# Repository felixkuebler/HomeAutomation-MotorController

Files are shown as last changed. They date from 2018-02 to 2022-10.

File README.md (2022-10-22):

# Introduction
Due to the growing demand of iot devices for home automation this project presents an cheap, easy to use and "open source" alternative to brand Products such as Phillips Hue. Based on the ESP8266-12E, a small WiFi enabled chipset, these devices can be retrofitted in a variety of devices such as light switches, motor controllers and more.

Each home automation node will access your local wifi network and is configurable through a webpage hosted locally on the device itsself. Your network needs to provide a [mqtt](https://pagefault.blog/2017/03/02/using-local-mqtt-broker-for-cloud-and-interprocess-communication/) broker to enable communication between nodes thus enabling its full functionality. An easy to use webinterface as well as a mqtt broker is provided by [Openhab](https://www.openhab.org/).

# Motor Controller
This small module can be mounted on any [Nema17](http://reprap.org/wiki/NEMA_17_Stepper_motor) stepper motor and thereby enabling Wifi functionality. The built in [TMC2130](https://www.trinamic.com/) stepper driver provides virtually silent motor operation as well as resistance detection of the driveshaft. This feature eliminates the need for endstops or any other sensor inputs thus resulting in a small and easy to use form factor. 

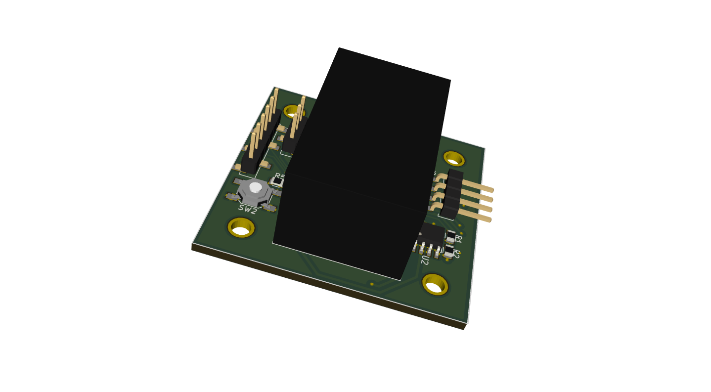
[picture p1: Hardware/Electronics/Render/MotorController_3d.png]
motor controller render


The current versions can be found here:
* *no release available*

# License
This work is property of Felix Kübler and is licensed under the
<a rel="license" href="http://creativecommons.org/licenses/by-nc/4.0/">Creative Commons Attribution-NonCommercial 4.0 International License</a>.

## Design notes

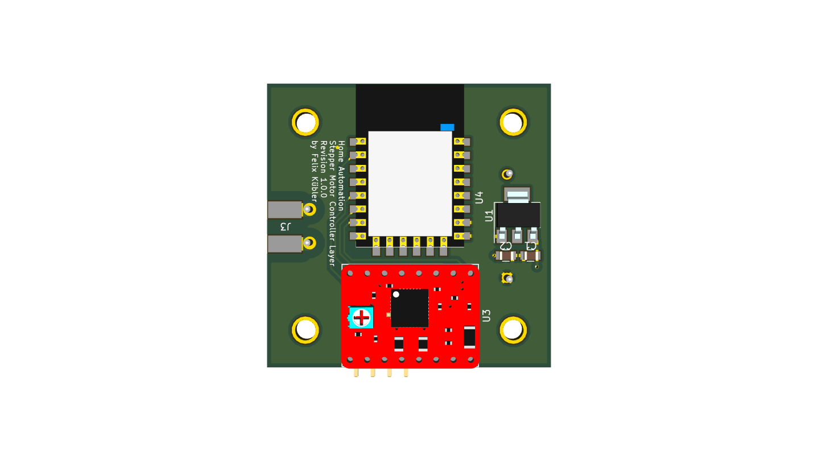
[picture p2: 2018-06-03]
Hardware/Electronics/Render/MotorController_bottom.png

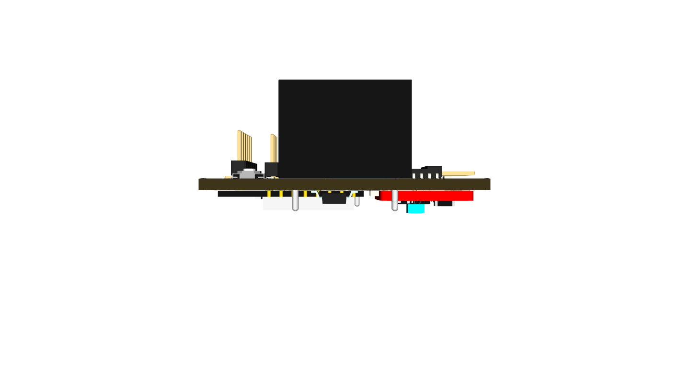
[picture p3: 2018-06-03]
Hardware/Electronics/Render/MotorController_right.png

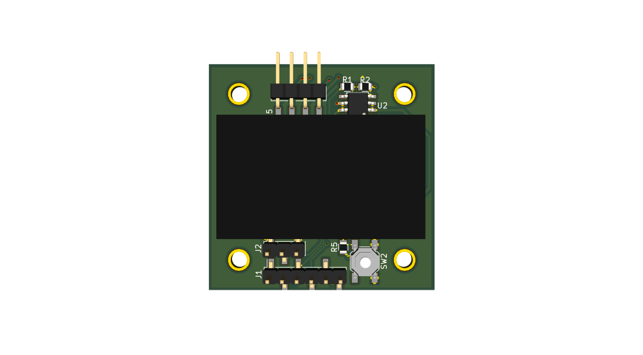
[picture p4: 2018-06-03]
Hardware/Electronics/Render/MotorController_top.png

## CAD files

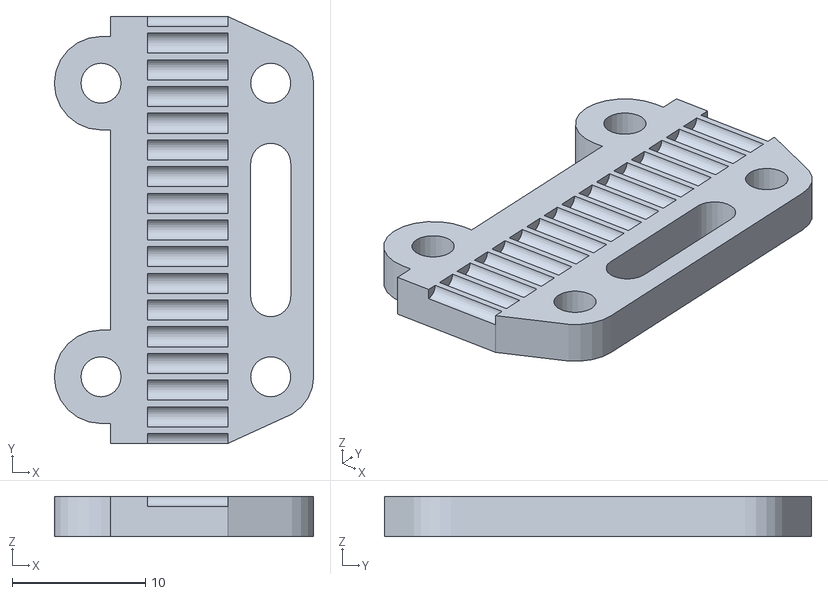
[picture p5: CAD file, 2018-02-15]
Hardware/Mechanics/PrintParts/BeltMountTeeth.stl
19.4 x 32.0 x 3.00

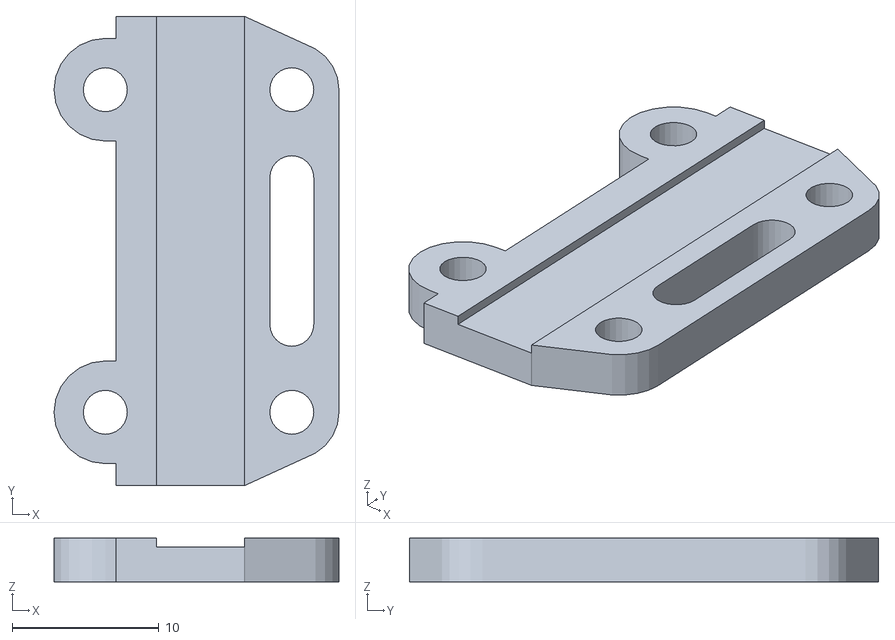
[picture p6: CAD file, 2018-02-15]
Hardware/Mechanics/PrintParts/BeltMountNoTeeth.stl
19.4 x 32.0 x 3.00

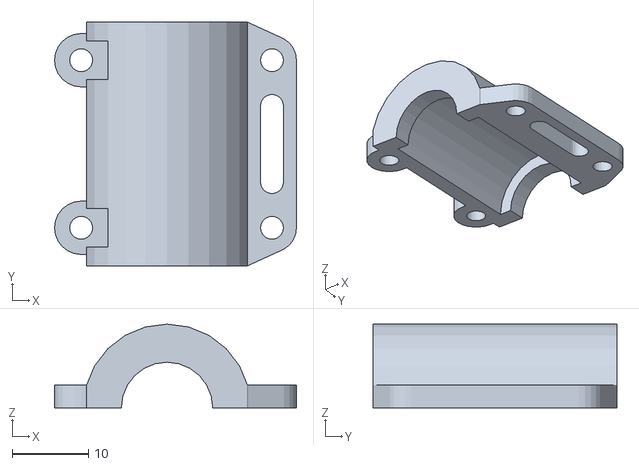
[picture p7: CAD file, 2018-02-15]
Hardware/Mechanics/PrintParts/BearingMount.stl
31.8 x 32.0 x 11.0

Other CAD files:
Hardware/TestAssembly/CAD/TestAssembly.skp

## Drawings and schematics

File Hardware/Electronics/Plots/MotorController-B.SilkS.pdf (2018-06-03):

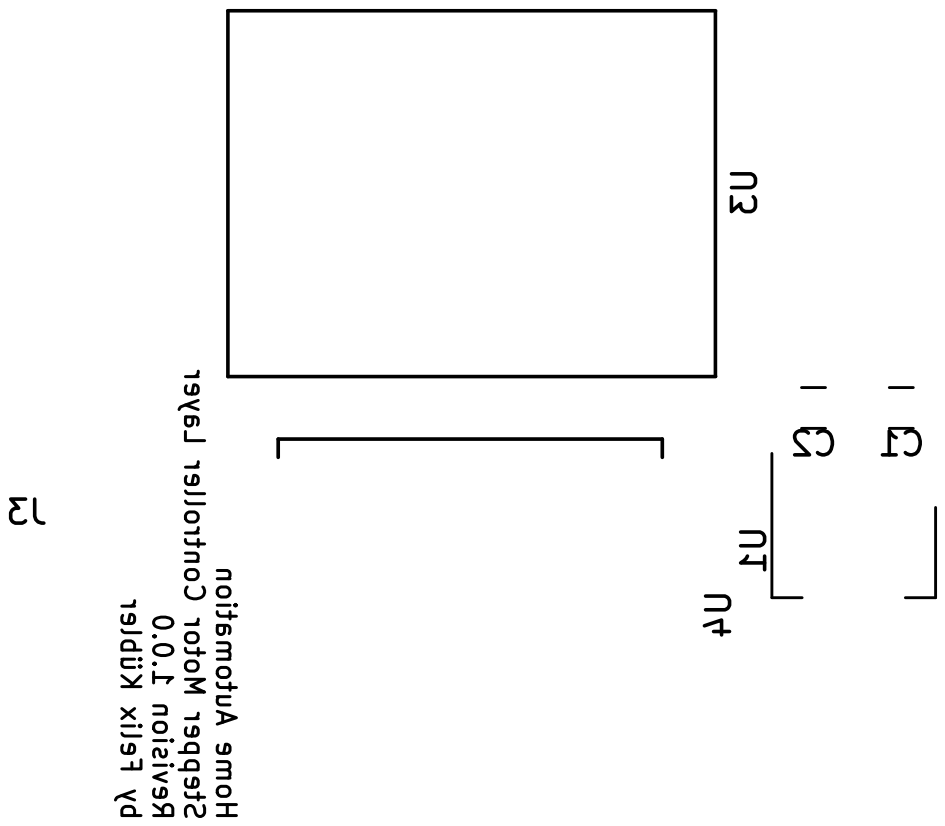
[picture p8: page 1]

by Felix Kübler Revision 1.0.0 Stepper Motor Controller Layer Home Automation U3 C2 C1 U1 U4

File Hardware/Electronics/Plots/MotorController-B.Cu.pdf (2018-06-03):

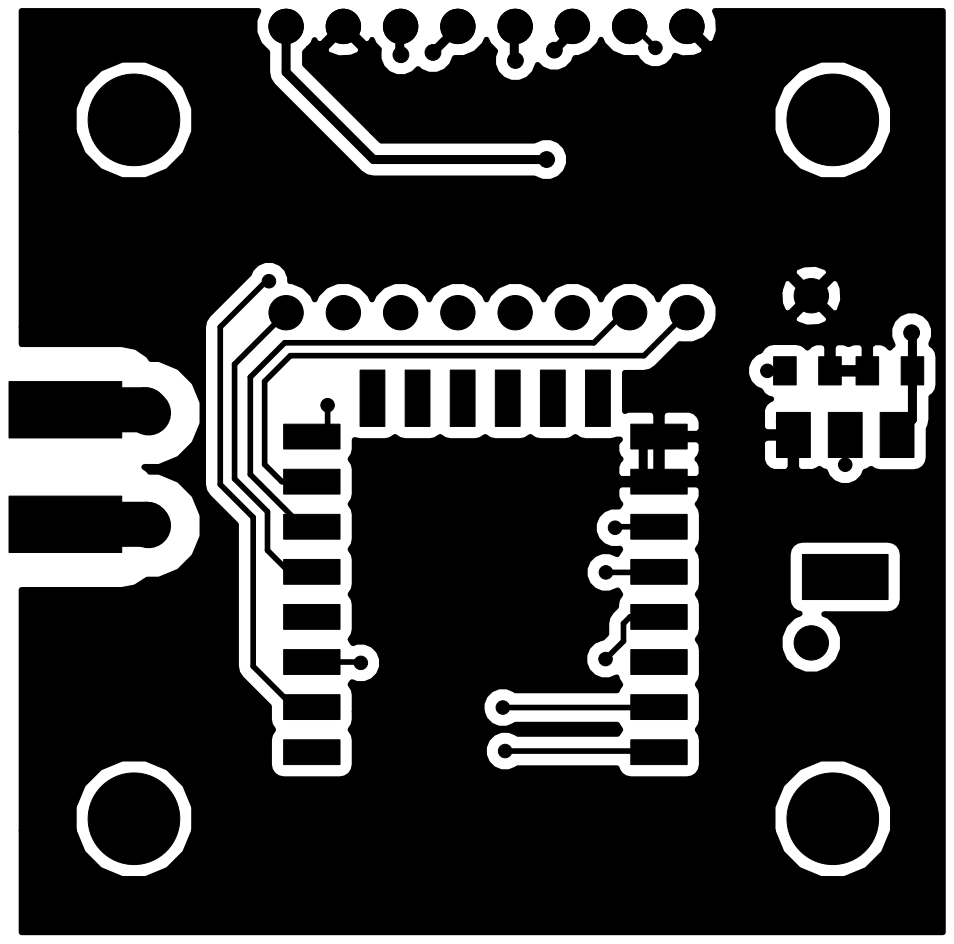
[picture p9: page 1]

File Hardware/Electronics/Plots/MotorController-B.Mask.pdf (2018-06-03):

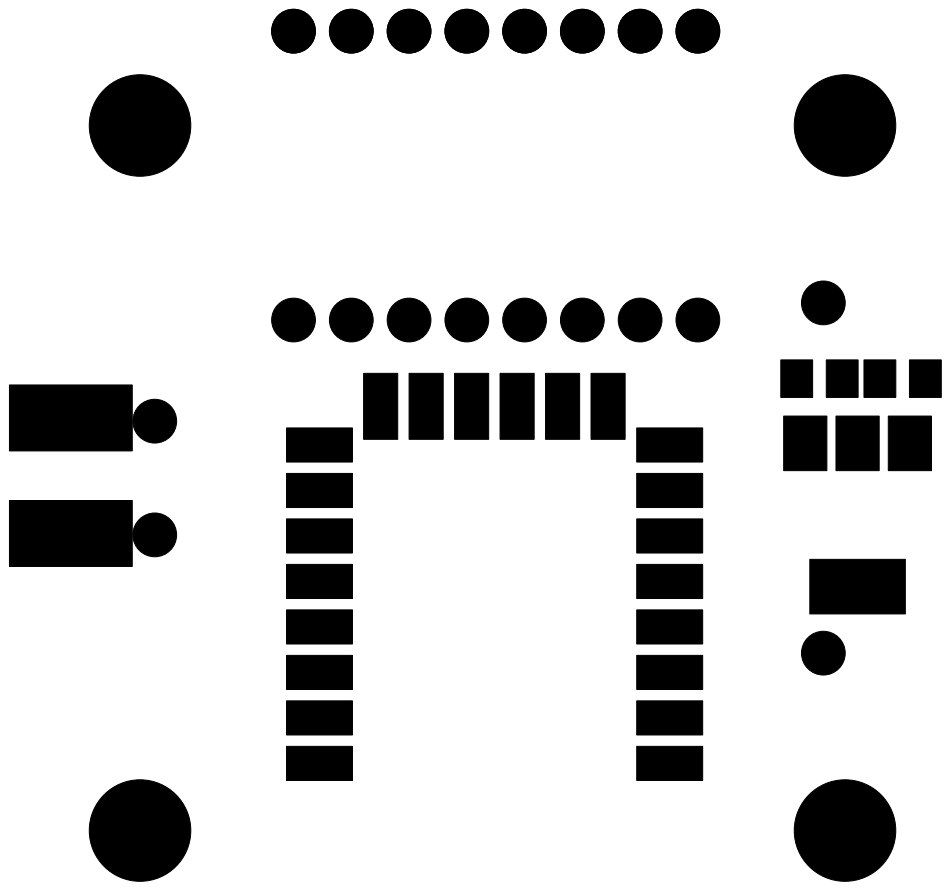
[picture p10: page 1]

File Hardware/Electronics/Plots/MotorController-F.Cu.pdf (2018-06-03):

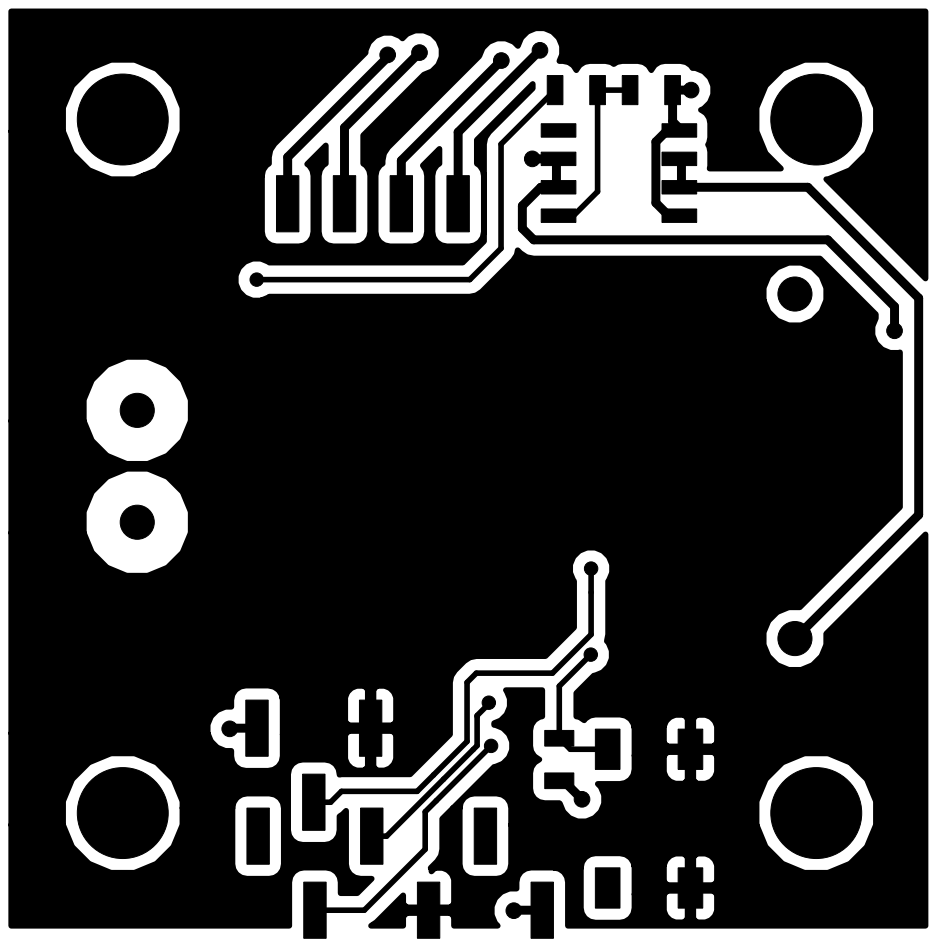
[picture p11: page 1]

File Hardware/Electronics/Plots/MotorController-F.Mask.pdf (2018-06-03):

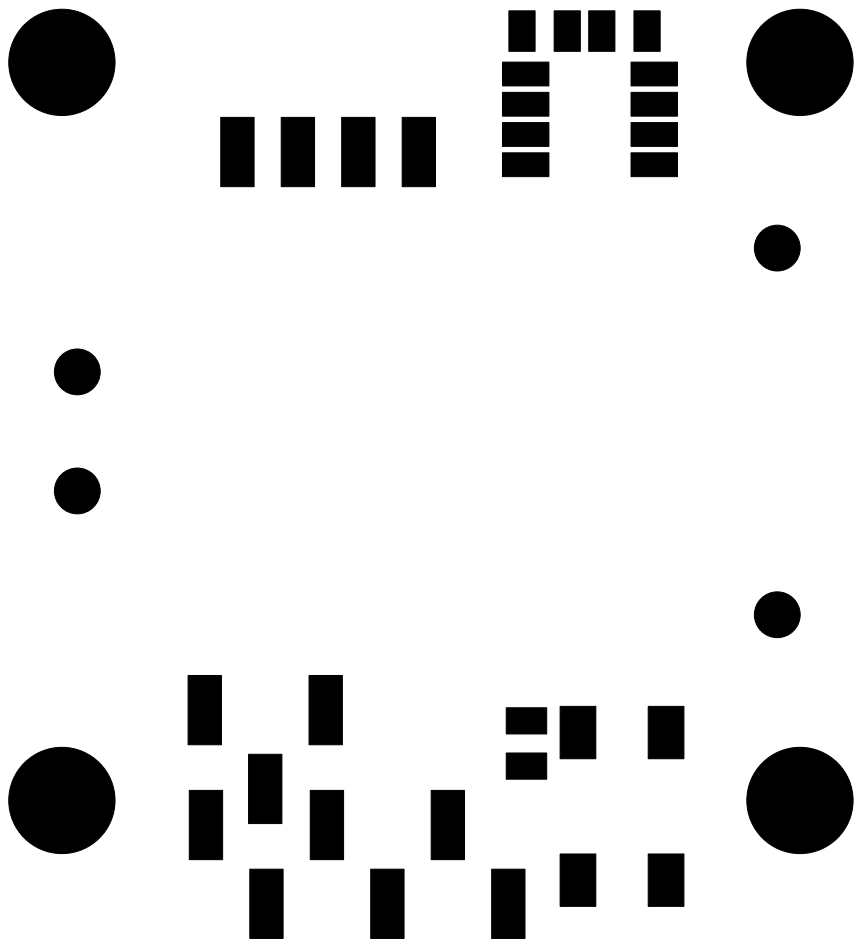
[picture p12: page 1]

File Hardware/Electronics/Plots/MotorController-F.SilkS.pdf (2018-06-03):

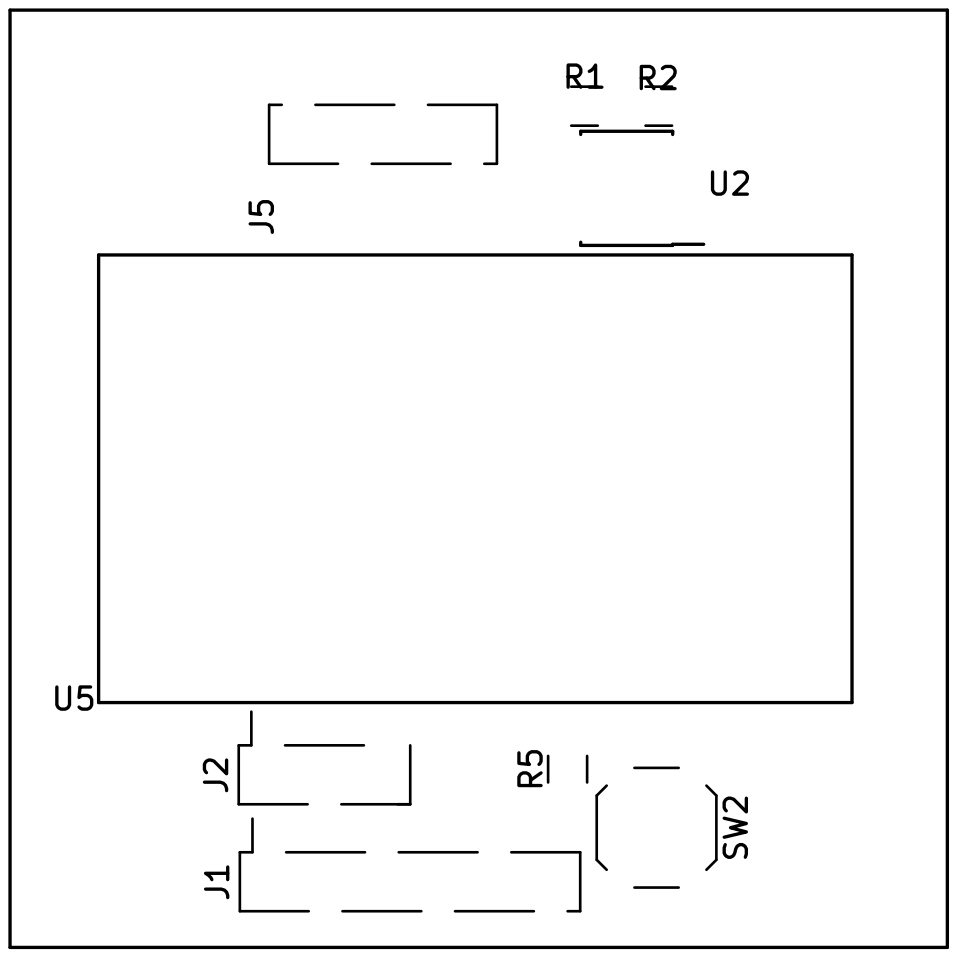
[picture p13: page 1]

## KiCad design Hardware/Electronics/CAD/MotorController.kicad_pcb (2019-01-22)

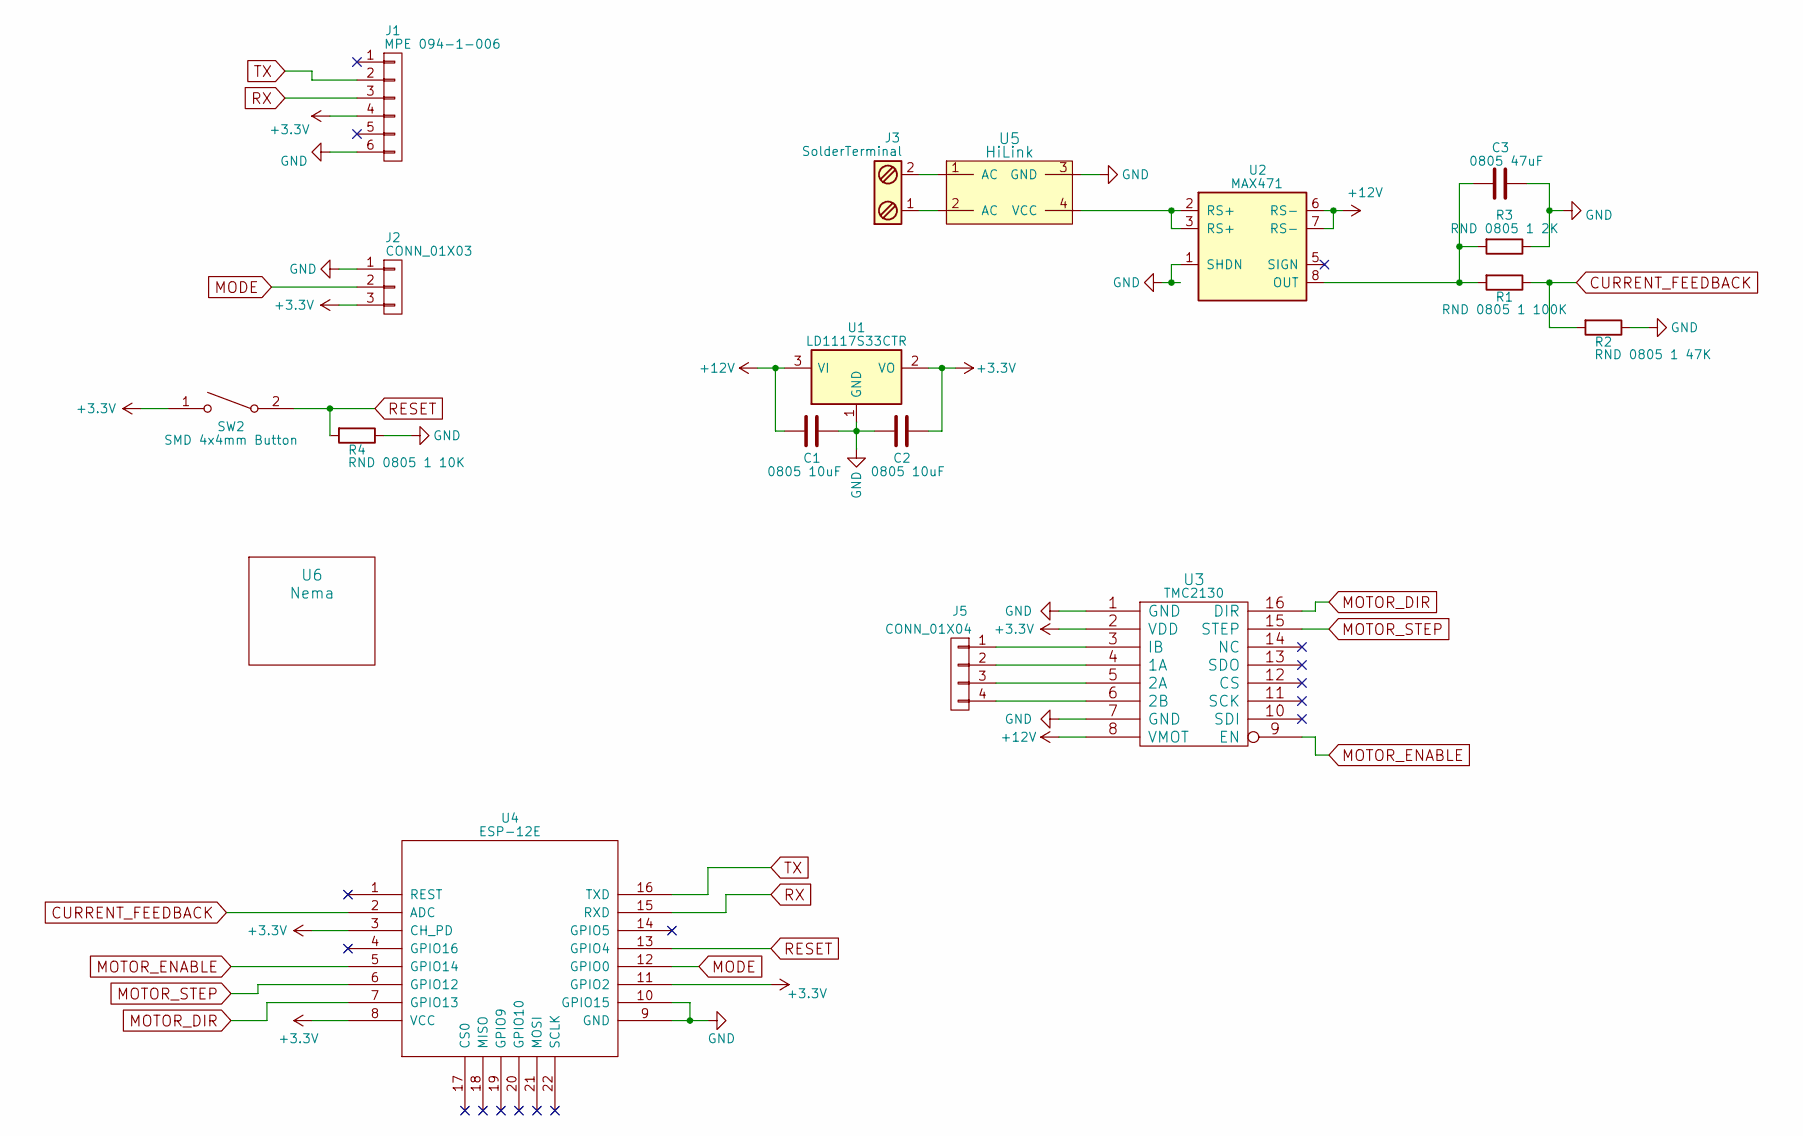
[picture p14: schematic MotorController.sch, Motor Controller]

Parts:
C1, C2: 0805 10uF; C_0805
C3: 0805 47uF; C_0805
J1: MPE 094-1-006; Pin_Header_Straight_1x06_Pitch2.54mm_SMD_Pin1Right
J2: CONN_01X03; Pin_Header_Straight_1x03_Pitch2.54mm_SMD_Pin1Right
J3: SolderTerminal; SolderPad_1x2_2.54mm
J5: CONN_01X04; Pin_Header_SMD_1x4_Angled_2.54mm
R1: RND 0805 1 100K; R_0805
R2: RND 0805 1 47K; R_0805
R3: RND 0805 1 2K; R_0805
R4: RND 0805 1 10K; R_0805
SW2: SMD 4x4mm Button; SW_SPST_SKQG
U1: LD1117S33CTR; SOT-223
U2: MAX471; SOIC-8_3.9x4.9mm_Pitch1.27mm
U3: TMC2130; TMC2230_SMD
U4: ESP-12E; ESP-12E_SMD
U5: HiLink; HLK-PM01
U6: Nema; Nema17

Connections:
+3V3: C2.1, J1.4, J2.3, SW2.1, U1.2 (VO), U3.2 (VDD), U4.3 (CH_PD), U4.8 (VCC), U4.11 (GPIO2)
+12V: C1.2, U1.3 (VI), U2.6 (RS-), U2.7 (RS-), U3.8 (VMOT)
CURRENT_FEEDBACK: R1.1, R2.2, U4.2 (ADC)
GND: C1.1, C2.2, C3.1, J1.6, J2.1, R2.1, R3.1, R4.1, U1.1 (GND), U2.1 (SHDN), U2.4 (GND), U3.1 (GND), U3.7 (GND), U4.9 (GND), U4.10 (GPIO15), U5.3 (GND)
MODE: J2.2, U4.12 (GPIO0)
MOTOR_DIR: U3.16 (DIR), U4.7 (GPIO13)
MOTOR_ENABLE: U3.9 (EN), U4.5 (GPIO14)
MOTOR_STEP: U3.15 (STEP), U4.6 (GPIO12)
unnamed: C3.2, R1.2, R3.2, U2.8 (OUT)
unnamed: J3.1, U5.2 (AC)
unnamed: J3.2, U5.1 (AC)
unnamed: J5.1, U3.3 (IB)
unnamed: J5.2, U3.4 (1A)
unnamed: J5.3, U3.5 (2A)
unnamed: J5.4, U3.6 (2B)
unnamed: U2.2 (RS+), U2.3 (RS+), U5.4 (VCC)
RESET: R4.2, SW2.2, U4.13 (GPIO4)
RX: J1.3, U4.15 (RXD)
TX: J1.2, U4.16 (TXD)

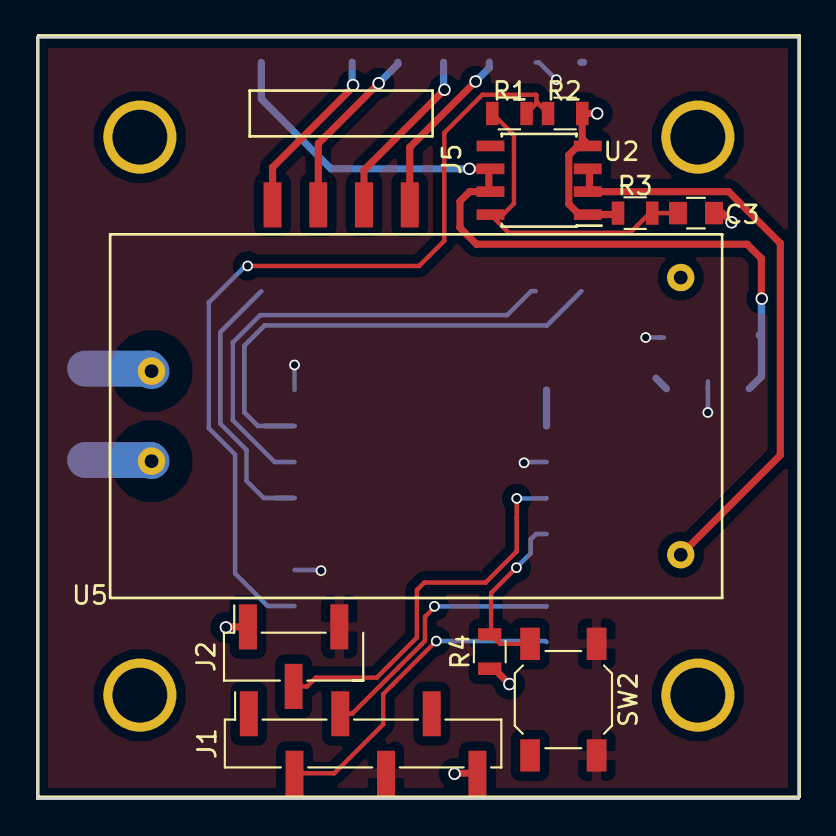
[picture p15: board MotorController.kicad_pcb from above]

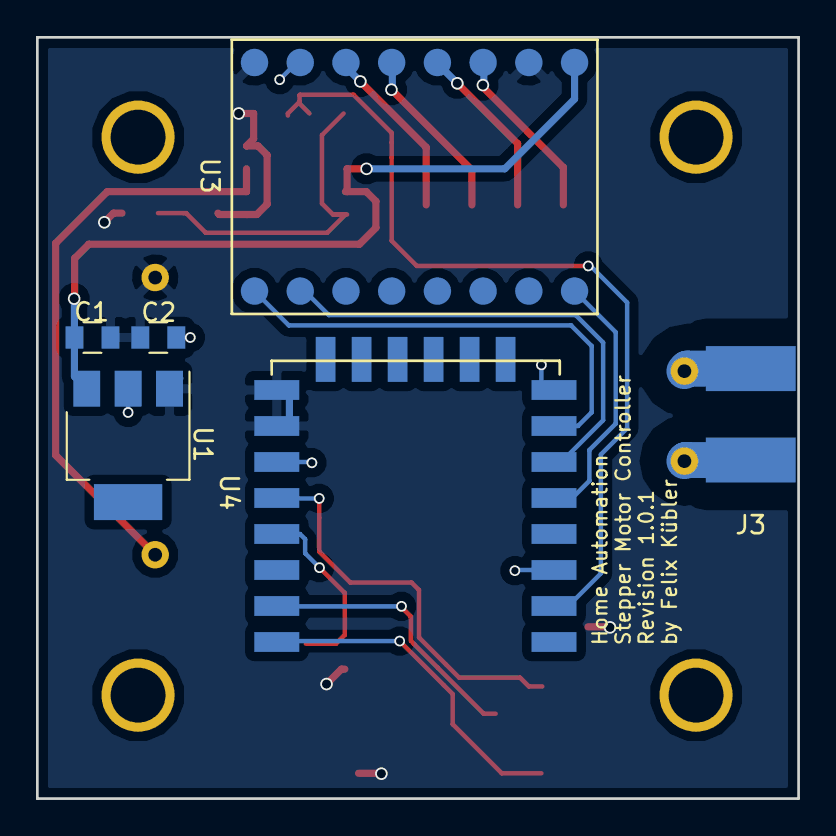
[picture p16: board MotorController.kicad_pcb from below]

Board: 2 copper layers, 42.3 x 42.3 mm, 18 parts (6 on the bottom side), 19 nets.

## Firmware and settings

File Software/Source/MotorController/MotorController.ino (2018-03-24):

#include <map>
#include <vector>

#include <ESP8266WiFi.h>

#include <DNSServer.h>
#include <ESP8266WebServer.h>
#include <WiFiClient.h> 
#include <PubSubClient.h>
#include <ESP8266HTTPUpdateServer.h>
#include <EEPROM.h>

#include "utils.h"
#include "motor_utils.h"
#include "wifi_utils.h"
#include "eeprom_utils.h"
#include "web_interface.h"


wifi_obj wifi_info;
motor_obj motor_info;

short int reset_pin;


DNSServer dnsServer;
ESP8266WebServer wifiServer(80);
WiFiClient wifiClient;
ESP8266HTTPUpdateServer wifiUpdater;
PubSubClient client(wifiClient);


CONFIG setup_type = default_config;
bool network_available = false;



/*
 * this function is called when a html request was send to the local html server
 */
void htmlHandleRequest() 
{
  //request counter
  short int request_count = 0;
  
  //get ssid request message from client
  String val = wifiServer.arg("wifi_ssid");
  //check if a message is not empty
  if(val.length()>0)
  {
    //set changes
    Serial.println("wifi_ssid : " + val);
    wifi_info.wifi_ssid = val;
    request_count++;
  }

  //get pw request message from client
  val = wifiServer.arg("wifi_pw");
  //check if a message is not empty
  if(val.length()>0)
  {
    //set changes
    Serial.println("wifi_pw : " + val);
    wifi_info.wifi_pw = val;
    request_count++;
  }

  //get host name request message from client
  val = wifiServer.arg("host_name");
  //check if a message is not empty
  if(val.length()>0)
  {
    //set changes
    Serial.println("host name : " + val);
    wifi_info.host_name = val;
    request_count++;
  }

  //get host name request message from client
  val = wifiServer.arg("host_pw");
  //check if a message is not empty
  if(val.length()>0)
  {
    //set changes
    Serial.println("host pw : " + val);
    wifi_info.host_pw = val;
    request_count++;
  }
  
  //get mqtt broker request message from client
  val = wifiServer.arg("mqtt_broker");
  //check if a message is not empty
  if(val.length()>0)
  {
    //set changes
    Serial.println("mqtt broker : " + val);
    wifi_info.mqtt_broker = val;
    request_count++;
  }

  //get motor topic request message from client
  val = wifiServer.arg("motor_topic");
  //check if a message is not empty
  if(val.length()>0)
  {
    //set changes
    Serial.println("motor_topic : " + val);
    motor_info.topic = val;
    request_count++;
  }

  //get motor range_extern request message from client
  val = wifiServer.arg("motor_range_extern");
  //check if a message is not empty
  if(val.length()>0)
  {
    //set changes
    Serial.println("motor_range_extern : " + val);
    motor_info.range_extern = val;
    request_count++;
  }

  //get motor calibration command request message from client
  val = wifiServer.arg("motor_calibration");
  //check if a message is not empty
  if(val.length()>0)
  {
    //set changes
    Serial.println("motor calibration triggered");
    calibrateMotor(motor_info);
    request_count++;
  }

  //get reset trigger from client
  String reset_settings = wifiServer.arg("reset_settings");
  //check if a reset was triggered
  if(reset_settings.length()>0)
  {
    Serial.println("System Settings set to default");
    //write reset flag to eeprom to use after a system reboot
    writeCharToEEPROM(0, 0);

    //reboot system
    ESP.eraseConfig();
    ESP.reset();
  }

  //get save trigger from client
  String save_settings = wifiServer.arg("save_settings");
  //check if reboot was triggered
  if(save_settings.length()>0)
  {
    Serial.println("user settings saved, system is going to restart");

    //save local changes to eeprom
    saveSettingsToEEPROM(wifi_info, motor_info);
    writeCharToEEPROM(0, 1);
    
    //reboot system
    ESP.eraseConfig();
    ESP.reset();
  }

  //give wifiServer new webpage
  wifiServer.send(200, "text/html", generateWebpage(wifi_info, motor_info));
}


/*
 * this function is called when a mqtt post was received
 */
void mqttSubscribeCallback(char* topic, byte* payload, unsigned int length) 
{  

  //turn byte* into String
  String msg ="";
  for(int i=0; i<length; i++)
  {
    msg+=(char)payload[i];
  }

  Serial.print("mqtt post \"");
  Serial.print(msg);
  Serial.print("\" on topic \"");
  Serial.print(topic);
  Serial.println("\" received");
  
  short int val = msg.toInt();
  
  if (val>=0 && val<=motor_info.range_extern.toInt())
  {
    //TODO
    long increment = motor_info.range_intern.toInt() / motor_info.range_extern.toInt();
    long new_state = increment*val;
    long old_state = motor_info.state;
    long diff = new_state-old_state;

    short int dir = HIGH;
    short int sign = 1;
    if (diff < 0)
    {
      dir = !dir;
      diff*=-1;
      sign = -1;
    }  

    digitalWrite(motor_info.pin_dir, dir);
    digitalWrite(motor_info.pin_enable, LOW);

    double current = analogRead(motor_info.pin_current);
    long steps = 0;
    bool enable_thresh = false;
    for ( ; steps < diff; steps++)
    {
      if (!enable_thresh && current >= motor_info.activation_thresh && current < motor_info.upper_thresh)
      {
        enable_thresh = true;
      }
      
      digitalWrite(motor_info.pin_step, !digitalRead(motor_info.pin_step));
      delay(0);
    
      if( enable_thresh && isStallDetected(motor_info, current))
      {    
        Serial.println("Stall Detected!");
        break;
      }

    }
    motor_info.state =  motor_info.state + (sign*steps);
    
    digitalWrite(motor_info.pin_enable, HIGH);

  }
  else
  {
    Serial.print("received value is out of range_extern");  
  }
  delay(10);
}

/*
 * this function is called a interrupt was triggerd on an input pin
 */
void mqttPublishCallback() 
{  
  //client.publish((it->second.topic).c_str(), (it->second.on_command).c_str());
}

/*
 * this function tryes to reconnect the mqtt client to the mqtt broker
 */
void mqttReconnect() 
{
  //repeat until a connection is astablished
  if (!client.connected()) 
  {
    Serial.print("attempting mqtt connection to ");
    Serial.print(wifi_info.mqtt_broker);
    Serial.print(" as ");
    Serial.print(wifi_info.host_name);
    Serial.print("...");
    
    // attempt to connect
    if (client.connect(wifi_info.host_name.c_str()))
    {
      Serial.println("  ok");

      //add motor to mqtt subscriber list
      client.subscribe((motor_info.topic).c_str());
    } 
    else 
    {
      //print error value
      Serial.print("  fail, rc=");
      Serial.println(client.state());
    }
  }
}


/*
 * this function will setup all wifi functions
 */
void wifi_setup(char reset_byte)
{
  //check reset indicatior
  if(reset_byte==0)
  {
    //reset was applied
    Serial.println("0  -> reset to default config");
    
    //save default settings to eeprom
    Serial.println("save default settings to epprom");
    Serial.print(wifiToString(wifi_info));
    Serial.print(motorToString(motor_info));
    saveSettingsToEEPROM(wifi_info, motor_info);

    //start access point for settings configuration 
    Serial.println("start access point");
    WiFi.softAPdisconnect(true);
    WiFi.disconnect();
    WiFi.mode(WIFI_AP);
    delay(100);
    WiFi.hostname(wifi_info.host_name);
    WiFi.softAPConfig(IPAddress(192, 168, 1, 1), IPAddress(192, 168, 1, 1), IPAddress(255, 255, 255, 0));
    WiFi.softAP(wifi_info.host_name.c_str());

    Serial.println("start dns captive portal");
    dnsServer.start(53, "*", IPAddress(192, 168, 1, 1));

    setup_type = default_config;
  }
  else
  {
    //reset was not applied
    Serial.println("1  -> load user config");

    //load settings from eeprom, make backup of wifi_info
    Serial.println("load settings from epprom");
    wifi_obj wifi_info_backup = wifi_info;
    loadSettingsFromEEPROM(wifi_info, motor_info);
    Serial.print(wifiToString(wifi_info));
    Serial.print(motorToString(motor_info));
    
    //connect to wifi network
    Serial.println("start as wifi client station");
    WiFi.softAPdisconnect(true);
    WiFi.disconnect();
    WiFi.mode(WIFI_STA);
    delay(100);
    WiFi.hostname(wifi_info.host_name);

    if(wifi_info.wifi_pw.length()>0)
    {
      WiFi.begin(wifi_info.wifi_ssid.c_str(), wifi_info.wifi_pw.c_str());
    }
    else
    {
      WiFi.begin(wifi_info.wifi_ssid.c_str());
    }

    //wait for wifinetwork, timeout after 20 seconds
    Serial.print("connecting to ");
    Serial.print(wifi_info.wifi_ssid);
    Serial.print("...");
    bool timeout = false;
    for(int timer = 0; WiFi.status() != WL_CONNECTED; timer++)
    {
      delay(500);
      Serial.print(".");

      if(timer>=40)
      {
        timeout = true;
        break;
      }
    }

    //check if timeout occured
    if(timeout)
    {
      //timeout was triggered
      Serial.println(" fail");
      
      //start access point if connection to network not possible
      Serial.println("start as accesspoint");
      WiFi.softAPdisconnect(true);
      WiFi.disconnect();
      WiFi.mode(WIFI_AP);
      delay(100);
      WiFi.hostname(wifi_info.host_name);
      WiFi.softAPConfig(IPAddress(192, 168, 1, 1), IPAddress(192, 168, 1, 1), IPAddress(255, 255, 255, 0));

      if(wifi_info.host_pw.length()>0)
      {
        WiFi.softAP(wifi_info.host_name.c_str(), wifi_info.host_pw.c_str());
      }
      else
      {
        WiFi.softAP(wifi_info.host_name.c_str());
      }

      Serial.println("start dns captive portal");
      dnsServer.start(53, "*", IPAddress(192, 168, 1, 1));

      setup_type=backup_config;

      network_available = networkAvailable(wifi_info.wifi_ssid);

    }
    else 
    {
      //no timeout
      Serial.println(" ok");

      //start mqtt client
      Serial.println("start mqtt pub/sub client");
      client.setServer(wifi_info.mqtt_broker.c_str(), 1883);
      client.setCallback(mqttSubscribeCallback);

      setup_type = user_config;
    }
  }
    
  //define request actions
  wifiServer.onNotFound(htmlHandleRequest);

  //start http server
  Serial.println("start http server");
  wifiUpdater.setup(&wifiServer);
  wifiServer.begin();
}


/*
 * on system boot this function is called once for setup purposes
 */
void setup(void)
{
  //start serial connection
  Serial.begin(9600);

  //add default wifi info
  wifi_info = wifi_obj("HA_Node_005");

  //add default motor info
  motor_info = motor_obj("motor_1", 14, 13, 12, A0);
  reset_pin = 4;

  //define eeprom space
  EEPROM.begin(512);

  //read first byte of eeprom as reset indicatior
  Serial.print("read reset byte from eeprom: ");
  char reset_byte;
  readCharFromEEPROM(0, reset_byte);
  
  wifi_setup(reset_byte);
}


/*
 * main loop that evaluates dns, wifiServer and mqtt events
 */
void loop(void)
{
  //check if a connection to network was established
  if(setup_type==user_config)
  {
    //try to connect to mqtt broker
    mqttReconnect();

    //if connection lost reboot
    if(WiFi.status() != WL_CONNECTED)
    {
      WiFi.softAPdisconnect(true);
      WiFi.disconnect();
      delay(100);
      wifi_setup(1);
      
      //reboot system
      //ESP.eraseConfig();
      //ESP.reset();
    }
  }
  else if(setup_type==backup_config)
  {
    //check if a network exists that matches the users network that did not exist before
    if(!network_available)
    {
      if(networkAvailable(wifi_info.wifi_ssid))
      {
        WiFi.softAPdisconnect(true);
        WiFi.disconnect();
        delay(100);
        wifi_setup(1);
      
        //reboot system
        //ESP.eraseConfig();
        //ESP.reset();
      }
    }
  }

  //repeat following commands 100 times before next mqtt reconnect attempt
  for (short int timeout = 0; timeout < 100; timeout++)
  { 
    //check if a connection to network was established
    if(setup_type==user_config)
    {
      //handle mqtt client
      client.loop();
      mqttPublishCallback();
    }

    dnsServer.processNextRequest();
    wifiServer.handleClient();

    delay(50);
  }

  //check for hardware reset
  if(digitalRead(reset_pin)==HIGH)
  {
    /*
    Serial.print("reset button high");
    writeCharToEEPROM(0, 0);
    ESP.eraseConfig();
    ESP.reset();
    */
  }
}

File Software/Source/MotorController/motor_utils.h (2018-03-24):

#ifndef MOTOR_UTILS
#define MOTOR_UTILS

struct motor_obj
{
  String topic;
  
  short int pin_enable;
  short int pin_dir;
  short int pin_step;

  short int pin_current;

  String range_intern;
  String range_extern;
  
  long state;

  double factor = 0.6;
  double analog_noise_thresh = 0.2;
  double upper_thresh = 115;
  double lower_thresh = 90;
  double activation_thresh = 100;

  motor_obj(): topic(""), pin_enable(0), pin_dir(0), pin_step(0), pin_current(0), range_intern("100"), range_extern("100"), state(0) {}

  motor_obj(String topic, short int pin_enable, short int pin_dir, short int pin_step, short int pin_current)
  : topic(topic), pin_enable(pin_enable), pin_dir(pin_dir), pin_step(pin_step), pin_current(pin_current), range_extern("100"), state(0) 
  {
    pinMode(pin_enable, OUTPUT);
    pinMode(pin_dir, OUTPUT);
    pinMode(pin_step, OUTPUT);

    pinMode(pin_current, INPUT);

    digitalWrite(pin_enable, HIGH);
  }

};

bool isStallDetected(motor_obj &motor_info, double &current)
{
   
  double analog_current = analogRead(motor_info.pin_current);
  if (analog_current > current + motor_info.analog_noise_thresh)
  {
    current = (current + motor_info.analog_noise_thresh) + motor_info.factor * (current - (current + motor_info.analog_noise_thresh));
  }
  else if (analog_current < current - motor_info.analog_noise_thresh)
  {
    current = (current - motor_info.analog_noise_thresh) + motor_info.factor * (current - (current - motor_info.analog_noise_thresh));
  }
  else
  {
    current = analog_current + motor_info.factor * (current - analog_current);
  }


  return current > motor_info.upper_thresh || current < motor_info.lower_thresh;
}

void calibrateMotor(motor_obj &motor_info)
{
  digitalWrite(motor_info.pin_enable, LOW);
  digitalWrite(motor_info.pin_dir, LOW);

  double current = analogRead(motor_info.pin_current);
  bool enable_thresh = false;
  while (true)
  {
    if (!enable_thresh && current >= motor_info.activation_thresh && current < motor_info.upper_thresh)
    {
      enable_thresh = true;
    }
    
    digitalWrite(motor_info.pin_step, !digitalRead(motor_info.pin_step));
    delay(0);
  
    if( enable_thresh && isStallDetected(motor_info, current))
    {    
      break;
    }
  }
  digitalWrite(motor_info.pin_enable, HIGH);

  delay(500);

  digitalWrite(motor_info.pin_enable, LOW);
  digitalWrite(motor_info.pin_dir, HIGH);

  current = analogRead(motor_info.pin_current);
  enable_thresh = false;
  long step_counter = 0;
  while (true)
  {
    if (!enable_thresh && current >= motor_info.activation_thresh && current < motor_info.upper_thresh)
    {
      enable_thresh = true;
    }
    
    digitalWrite(motor_info.pin_step, !digitalRead(motor_info.pin_step));
    delay(0);
  
    if( enable_thresh && isStallDetected(motor_info, current))
    {    
      break;
    }

    step_counter++;
  }

  digitalWrite(motor_info.pin_enable, HIGH);

  motor_info.range_intern = String(step_counter);
}

String motorToString(motor_obj motor_info)
{
  String str;
  str += "motor topic : " + motor_info.topic + "\n";
  str += "motor range_intern : " + motor_info.range_intern + "\n";
  str += "motor range_extern : " + motor_info.range_extern + "\n";
  return str;
}

  
#endif //MOTOR_UTILS

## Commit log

2018-02-15 motor controller single repo setup
    [BearingMount.stl, BeltMountNoTeeth.stl, BeltMountTeeth.stl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]
2018-02-23 home automation iplementation of motor controller software
    [MotorController.sch]
2018-03-24 new software file structure
    [MotorController.sch]
2018-04-08 kicad linkage fix
2018-04-08 revision1.0.0 for electrical hardware
    [MotorController.kicad_pcb, MotorController.sch]
2018-06-03 library changes
    [MotorController.sch]
2018-06-03 gerber files
    [MotorController-B.Cu.gbr, MotorController-B.Mask.gbr, MotorController-B.SilkS.gbr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]
2018-06-03 new renderings
    [MotorController.kicad_pcb]
2018-06-28 test excel
    [Mappe1.xlsx]
2018-06-28 test finished
    [Mappe1.xlsx]
2018-07-29 bug fix current sensor
    [MotorController.kicad_pcb, MotorController.sch, MotorController.xml]
2018-08-29 MAX741 missing resistor fix
    [MotorController.kicad_pcb, MotorController.sch]
2018-08-29 additional capacitor for current sensor smoothing
    [MotorController.sch]
2018-09-01 part reference cleanup
    [MotorController.kicad_pcb]
2018-09-03 test assembly
    [TestAssembly.skp]
2018-09-03 library linkage fix
    [MotorController.kicad_pcb, MotorController.sch, MotorController.xml]
2018-09-05 terminal footprints
    [MotorController.sch]
2018-09-23 housing for pcb
2019-01-22 new gerber files
    [MotorController-B.Cu.gbr, MotorController-B.Mask.gbr, MotorController-B.SilkS.gbr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]
